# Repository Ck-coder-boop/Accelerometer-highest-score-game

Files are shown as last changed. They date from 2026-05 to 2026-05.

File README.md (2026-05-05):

# Motion-Based Reaction Game (STM32)

## Overview
This project implements a motion-controlled reaction game using an STM32 microcontroller.  
The user responds to directional prompts by tilting the device, with performance tracked through a scoring and high-score system.

The system integrates multiple peripherals including an accelerometer, display, RGB LED, and push button, with additional features such as timing constraints, input filtering, and low-power idle behaviour.

---

## Circuit Schematic
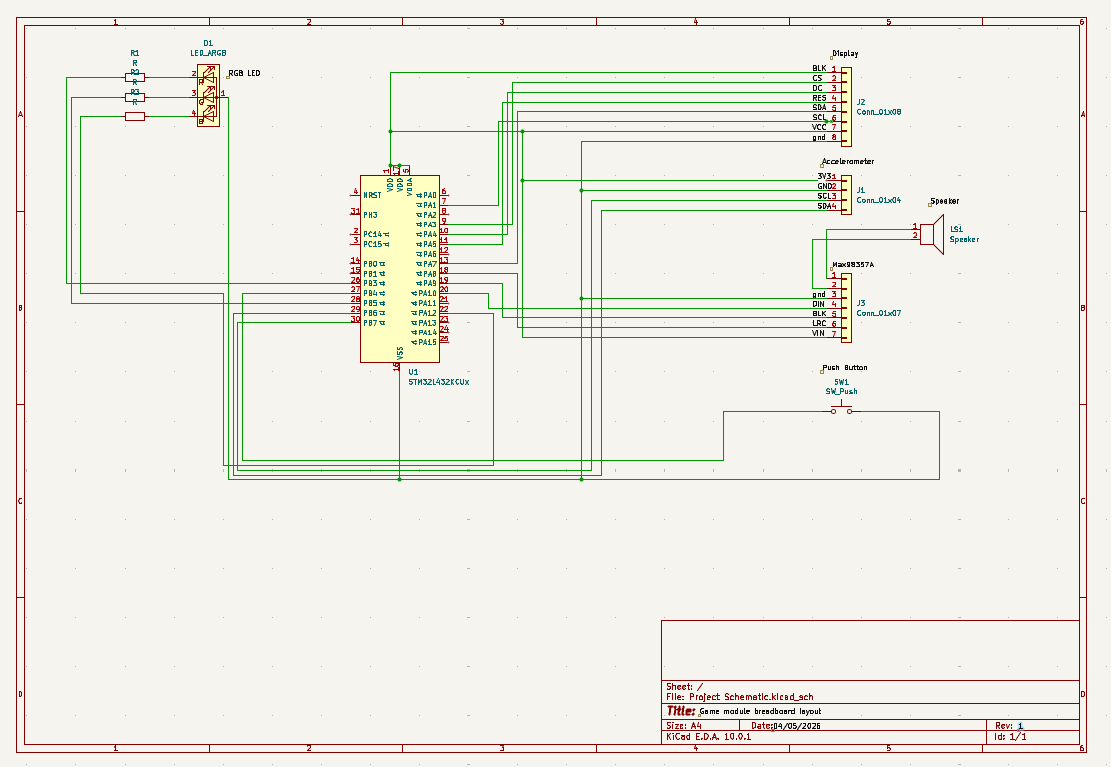
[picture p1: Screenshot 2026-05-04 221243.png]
Circuit schematic


---

## Hardware Components
- **STM32 Nucleo-L432KC** – Main controller handling logic and timing  
- **Accelerometer (I2C)** – Detects motion and tilt direction  
- **Push Button** – Starts the game and wakes the system  
- **RGB LED** – Indicates system state (idle, active, result)  
- **TFT Display (SPI)** – Displays instructions and score  
- **MAX98357A Audio Amplifier (Experimental)** – Attempted audio output  

---

## Documentation
- 📄 [Project Report](Embedded%20Systems%20Project%202.pdf)  
- 📝 [Rough Weekly Notes](Rough_notes.txt)  
- 🎥 [Demonstration Video](https://youtu.be/MFnngxhUEXM)  

---

## Source Code

### Core Application
- [main.c](main.c) – Main game logic, timing, and state control  

### Peripheral Drivers
- [display.c](display.c) / [display.h](display.h) – TFT display control (text, graphics)  
- [i2c.c](i2c.c) / [i2c.h](i2c.h) – I2C communication (accelerometer interface)  
- [spi.c](spi.c) / [spi.h](spi.h) – SPI communication (display interface)  
- [eeng1030_lib.c](eeng1030_lib.c) / [eeng1030_lib.h](eeng1030_lib.h) – Utility functions (GPIO, timing, delays)  

### Data Files
- [sound_array.h](sound_array.h) – Stored audio sample data (experimental playback)  

---

## Hardware Files
- 📐 [Schematic (PDF)](Schematicpdf.pdf)  
- 🖼️ [Breadboard Setup Image](Screenshot%202026-05-04%20221243.png)  

---

## System Features
- Motion-based input using accelerometer  
- Direction detection (left, right, forward, back)  
- Score and high-score tracking  
- Timeout-based gameplay  
- Neutral-zone filtering to prevent repeated inputs  
- RGB LED state indication  
- Low-power idle mode using CPU sleep (WFI)  
- Experimental audio playback using I2S  

---

## Notes
Audio output was investigated using a MAX98357A I2S amplifier.  
Although signal activity was observed, reliable playback was not achieved due to strict timing requirements for I2S communication when implemented in software. As a result, audio functionality was treated as experimental and was not included in the final system operation.

---

## Repository Structure (Summary)
- `main.c` → Game logic and control  
- Peripheral files → Hardware interfacing  
- `sound_array.h` → Audio data  
- Report + notes → Documentation  
- Schematic + image → Hardware design

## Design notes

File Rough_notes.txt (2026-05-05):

Week 1 – Setup and Planning
Set up STM32 environment and got previous assignment code running again
Initially wasn’t fully sure what direction to take with the project
Decided on a motion-based reaction game using the accelerometer
Didn’t get much actual implementation done this week

This week was mainly planning and getting everything working again from the previous assignment.

Week 2 – Basic Hardware + Early Issues
Started wiring up components on the breadboard
First attempt at display and button didn’t work properly
Spent time checking wiring with multimeter and fixing connections
Got button input working after fixing pull-up configuration
Display eventually worked after rechecking SPI connections

Progress was slower than expected due to wiring issues and getting used to the hardware again.

Week 3 – Core Game Logic
Got accelerometer readings working using I2C
Initially values were unstable → adjusted scaling and thresholds
First attempt at tilt detection was too sensitive
Added thresholds to detect left/right/forward/back properly
Implemented basic game loop
Tried input without neutral filtering → caused repeated triggering
Fixed this by adding a neutral zone before next input

This week involved a lot of trial and error to get reliable motion detection.

Week 4 – Features + Debugging
Added scoring system and high score tracking
Implemented timeout logic using millisecond timer
Button debounce added after noticing multiple triggers
RGB LED added for system state feedback
Tried adding audio output:
First tested speaker directly → no proper output
Created sound array and attempted playback → very weak signal
Added MAX98357A amplifier → only small click/buzz heard
Concluded issue likely due to I2S timing not being accurate
Left audio as experimental and focused on main functionality

Final week focused on refining the system and solving integration issues. Audio was attempted but not fully successful.

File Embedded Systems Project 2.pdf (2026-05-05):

# Embedded Systems Project 2 Improvements and Additional Features

EENG1030

Conor King – C22303056

Last Updated 05/05/2026

## Contents

This project presents a motion-based reaction game implemented on an STM32 microcontroller. The system uses an accelerometer to detect directional input and challenges the user to respond within a time constraint. Visual feedback is provided via an OLED display and RGB LED, while a high-score system tracks performance. Additional features include

Embedded systems are widely used in interactive applications requiring real-time input processing. This project builds on previous work by developing a motion-controlled reaction game using an STM32 platform. The system integrates multiple peripherals including an accelerometer, display, and LED indicators to create an interactive user experience. The objective was to design a responsive system with clear feedback, timing constraints, and

7.13 Audio Limitation | 11
Figure 1 Image of Real-Life Breadboard | 6
Figure 2 Schematic Design | 7

# 1. Abstract

This project presents a motion-based reaction game implemented on an STM32 microcontroller. The system uses an accelerometer to detect directional input and challenges the user to respond within a time constraint. Visual feedback is provided via an OLED display and RGB LED, while a high-score system tracks performance. Additional features include timeout logic, neutral position filtering, and low-power idle operation.

# 2. Introduction

Embedded systems are widely used in interactive applications requiring real-time input processing. This project builds on previous work by developing a motion-controlled reaction game using an STM32 platform. The system integrates multiple peripherals including an accelerometer, display, and LED indicators to create an interactive user experience. The objective was to design a responsive system with clear feedback, timing constraints, and efficient operation.

# 3. System Overview

- User presses button → game starts
- Display shows direction
- User tilts device
- System checks correctness
- Score updates
- Timeout or wrong input ends game
- High score stored

# 4. Hardware Description (Fig. 1)

## STM32 Nucleo (Controller)

- Acts as the central control unit of the system
- Executes all game logic, timing functions, and state transitions
- Interfaces with all peripherals (I2C, SPI, GPIO)
- Processes accelerometer data and determines user actions
The STM32 is responsible for coordinating all inputs and outputs in real time, ensuring that the system responds immediately to user interaction.

## Accelerometer (I2C)

- Measures acceleration in X and Y axes
- Used to detect directional tilt (left, right, forward, back)
- Provides the primary user input mechanism
- Communicates with STM32 via I2C protocol
The accelerometer replaces traditional buttons by allowing motion-based control, forming the core interaction method of the game.

## OLED Display (SPI)

- Displays game instructions (direction prompts)
- Shows current score and high score
- Provides real-time visual feedback to the user
- Communicates via SPI for fast data transfer
The display serves as the main user interface, allowing the player to understand system prompts and monitor performance.

## Push Button

- Used to start the game
- Wakes the system from idle (low-power mode)
- Configured with internal pull-up resistor
- Provides a simple digital input to the STM32
The push button acts as the system trigger, ensuring controlled startup and preventing accidental activation.

## RGB LED

- Provides quick visual indication of system state
- Colour-coded states:
- Red → Idle / waiting
- Blue → Game active
- Green → End of round
- Controlled via GPIO outputs
The RGB LED provides immediate feedback without needing to look at the display, improving usability and responsiveness.

## Speaker / Audio Module (Experimental)

- Intended to provide audio feedback for events such as high score
- Driven using digital signals from the STM32

- Attempted implementation using I2S (MAX98357A amplifier)
- Used sound data array for playback
The audio system was designed to enhance user feedback; however, due to strict timing requirements for I2S communication, reliable playback was not achieved. The module remains part of the design but is not critical to core functionality.

## Breadboard and Wiring

- Used to prototype and interconnect all components
- Provides flexible layout for rapid testing and modification
- Distributes power (3.3 V and GND) across all modules
The breadboard enables quick hardware iteration and testing, which was essential during debugging and system integration.

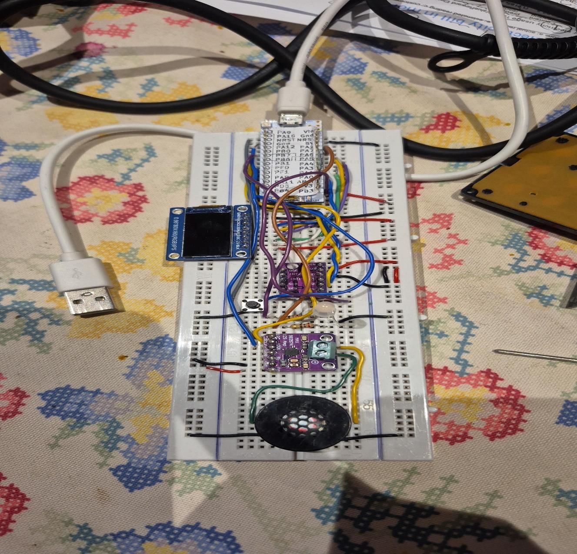
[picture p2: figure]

Figure 1 Image of Real-Life Breadboard

# 5. Circuit Schematic (Fig. 2)

The circuit schematic (Fig. 2) shows the interconnection between the STM32 microcontroller and all peripherals. Communication protocols include I2C for the accelerometer and SPI for the display. GPIO pins are used for button input, LED control, and audio output. Proper power and ground distribution are maintained across the system.

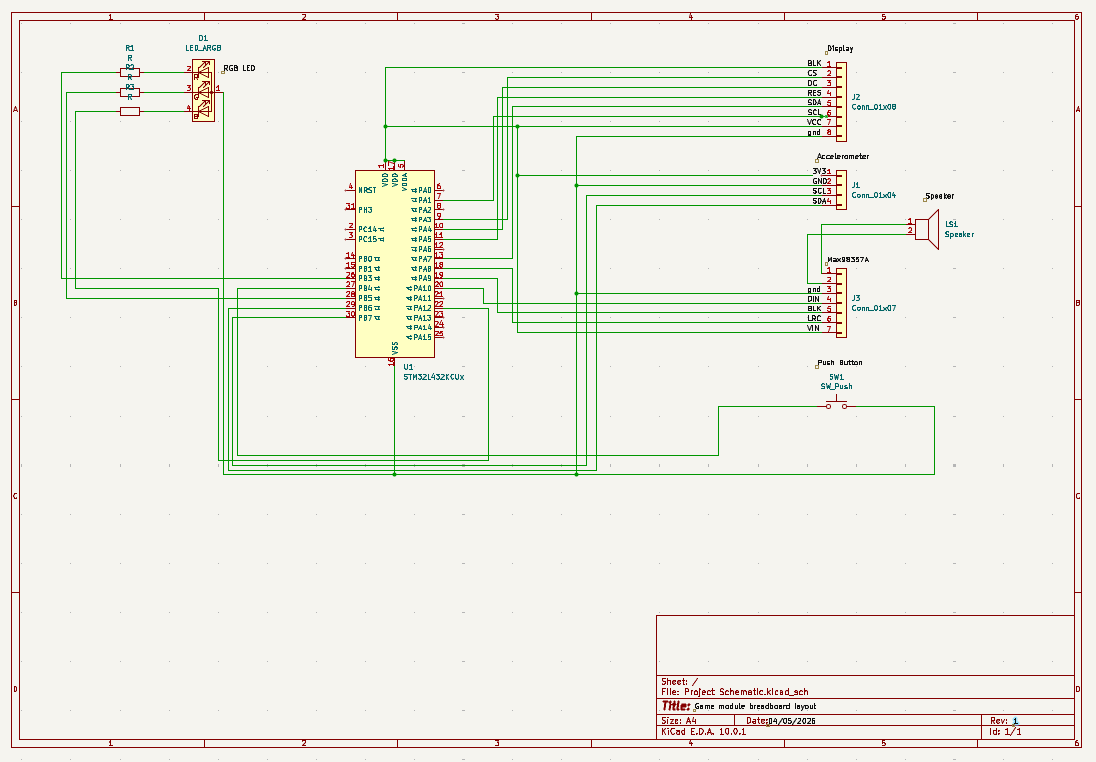
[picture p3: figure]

Figure 2 Schematic Design

# 6. Troubleshooting and Problem Solving

The system was developed using an incremental testing approach, where each component was verified individually before full integration. Basic electrical checks were first carried out using a multimeter to confirm correct voltage levels, common grounding, and continuity across the breadboard. Individual modules such as the push button, RGB LED, display, and accelerometer were then tested using small standalone code segments to ensure correct operation. This approach allowed faults to be isolated quickly and ensured that any issues encountered during full system integration were more likely related to software logic or communication timing rather than wiring errors.
During integration, timing-related behaviour and input reliability were refined through testing. The accelerometer thresholds were adjusted based on observed readings to ensure that only deliberate movements were detected, while a neutral zone was implemented to prevent repeated triggering. Buttons debounce delays were also introduced to eliminate false inputs. Visual feedback through the RGB LED was verified to correctly represent system states, and timeout logic was tested to ensure the game ended correctly when no input was detected within the specified time window.
A significant issue was encountered with the speaker and audio output. The speaker was initially tested directly from a GPIO output, where no meaningful audio signal was produced. A sound array generated externally was then used to drive the speaker, but only a very weak or brief signal was observed. When the MAX98357A amplifier module was introduced, a small click or buzz was detected, indicating that some signal was present, but no clear audio playback was achieved. This suggests that while the data was being transmitted, the timing requirements for proper I2S communication were not being met. As a result, audio functionality was considered experimental and was not relied upon for the final system, although the testing process confirmed partial signal activity and ruled out complete hardware failure. Time was no doubt a factor here too and some attempts were used just with small segments of code to get the operation working but again it seemingly refused to work.

# 7. Software Design

The software was structured so that each major function of the system is handled separately. The main program controls the game flow, while separate functions are used for accelerometer reading, tilt detection, display updates, RGB LED feedback, low-power idle mode, and experimental audio playback.

## 7.1 Timing Constants

#define ROUND_TIME_MS 4000

#define IDLE_SLEEP_MS 10000

#define DEBOUNCE_MS 250

#define RESULT_DISPLAY_MS 2000

These constants define the main timing behaviour of the system. The player has four seconds to respond to each displayed instruction. A debounce delay is used to prevent one button press from being detected multiple times, and the result screen remains visible for two seconds before returning to idle.

## 7.2 Button Start Logic

button = (BUTTON_PORT->IDR & (1 << BUTTON_PIN)) ? 1 : 0;

if ((last_button == 1) && (button == 0) && !running)
{
running = 1;
score = 0;
ready = 1;

action = next_action();
round_start_time = milliseconds; }

The push button uses an internal pull-up resistor, meaning the input is normally high and becomes low when pressed. The code detects this falling edge and starts a new game only when the system is not already running.

## 7.3 Random Action Generation

static uint8_t next_action(void)
{
static uint8_t count = 0;
count++;

return (uint8_t)((milliseconds + count * 7) % 4);
}
This function generates the next movement instruction. The system uses the current millisecond timer and an increasing counter to vary the output. The result is limited to four possible values: left, right, forward, and back.

## 7.4 Accelerometer Tilt Detection

static uint8_t detect_tilt(int32_t x, int32_t y)
{
if (y < 200 && y > -200)
{
if (x > X_THRESHOLD) return ACT_RIGHT; if (x < -X_THRESHOLD) return ACT_LEFT; }

if (x < 300 && x > -300)
{
if (y > Y_FORWARD_THRESHOLD) return ACT_FORWARD; if (y < Y_BACK_THRESHOLD) return ACT_BACK;
}

return ACT_NONE;
}
The accelerometer values are compared against threshold values to decide which direction the user has tilted the device. X-axis values are used for left and right movement, while Y-axis values are used for forward and back movement. If no threshold is exceeded, no action is detected.

## 7.5 Neutral Zone Filtering

if ((x < X_NEUTRAL_HIGH && x > X_NEUTRAL_LOW) &&
(y < Y_NEUTRAL_HIGH && y > Y_NEUTRAL_LOW))
{
ready = 1;
}

A neutral zone is used so that one tilt is not counted repeatedly. After a movement is detected, the user must return the board close to its neutral position before another input can be accepted.

## 7.6 Timeout Logic

if ((milliseconds - round_start_time) > ROUND_TIME_MS)
{
running = 0;
rgb_green();
draw_fail(score, high);
}
The timeout logic ends the game if the user does not respond within the allowed time. This creates the reaction-game behaviour and prevents the system from waiting indefinitely for input.

## 7.7 High Score Logic

if (score > high)
{
high = score;
rgb_green();
draw_high(score);
play_sound_file();
}
The high score is stored during runtime. If the player beats the previous high score, the display updates to show the new score and the stored audio sample is attempted through the audio output system.

## 7.8 RGB LED State Feedback

rgb_red(); // idle / waiting
rgb_blue(); // game active
rgb_green(); // result screen
The RGB LED acts as a quick system status indicator. Red shows the system is idle, blue shows the game is active, and green shows the end/result state. This gives feedback even when the user is not focused on the display.

## 7.9 Low-Power Idle Mode

static void enter_idle_sleep(void)
{
rgb_off();
__WFI();
}
The system enters a light sleep state after a period of inactivity. The __WFI() instruction places the CPU into a wait-for-interrupt mode, reducing unnecessary activity while preserving variables such as the high score.

## 7.10 Audio Sample Array

#include "sound_array.h"

const int16_t sound_data[] = {
3, 2, -1, -5, 5, -1,
};

const unsigned int sound_length =
sizeof(sound_data) / sizeof(sound_data[0]);
The audio sample is stored in a separate header file as signed 16-bit values. These values were generated from an external audio file and converted into a C array. This allows the sound data to be stored directly in the microcontroller flash memory.

## 7.11 Audio Playback Attempt

static void play_sound_file(void)
{
for (uint32_t i = 0; i < sound_length; i++) {
int16_t s = sound_data[i] * 3; i2s_send_stereo(s, s);
}
}
This function loops through the stored audio sample and sends each value to the audio output function. The sample is multiplied to increase amplitude before being sent to both left and right audio channels.

## 7.12 I2S Bit Transmission

static void i2s_send_stereo(int16_t left, int16_t right)
{
I2S_LRC_PORT->ODR &= ~(1 << I2S_LRC_PIN); i2s_send_word(left);

I2S_LRC_PORT->ODR |= (1 << I2S_LRC_PIN);
i2s_send_word(right);
}
The MAX98357A audio module uses I2S communication, requiring separate signals for bit clock, left/right clock, and data. This function attempts to send left and right channel audio samples by manually controlling the GPIO pins.

## 7.13 Audio Limitation

Again, although the audio sample was successfully stored and transmitted in software, reliable playback was not achieved. The MAX98357A requires accurately timed I2S signals, and software-based bit-banging was not accurate enough to produce clear sound. It is still unclear what the issue was.

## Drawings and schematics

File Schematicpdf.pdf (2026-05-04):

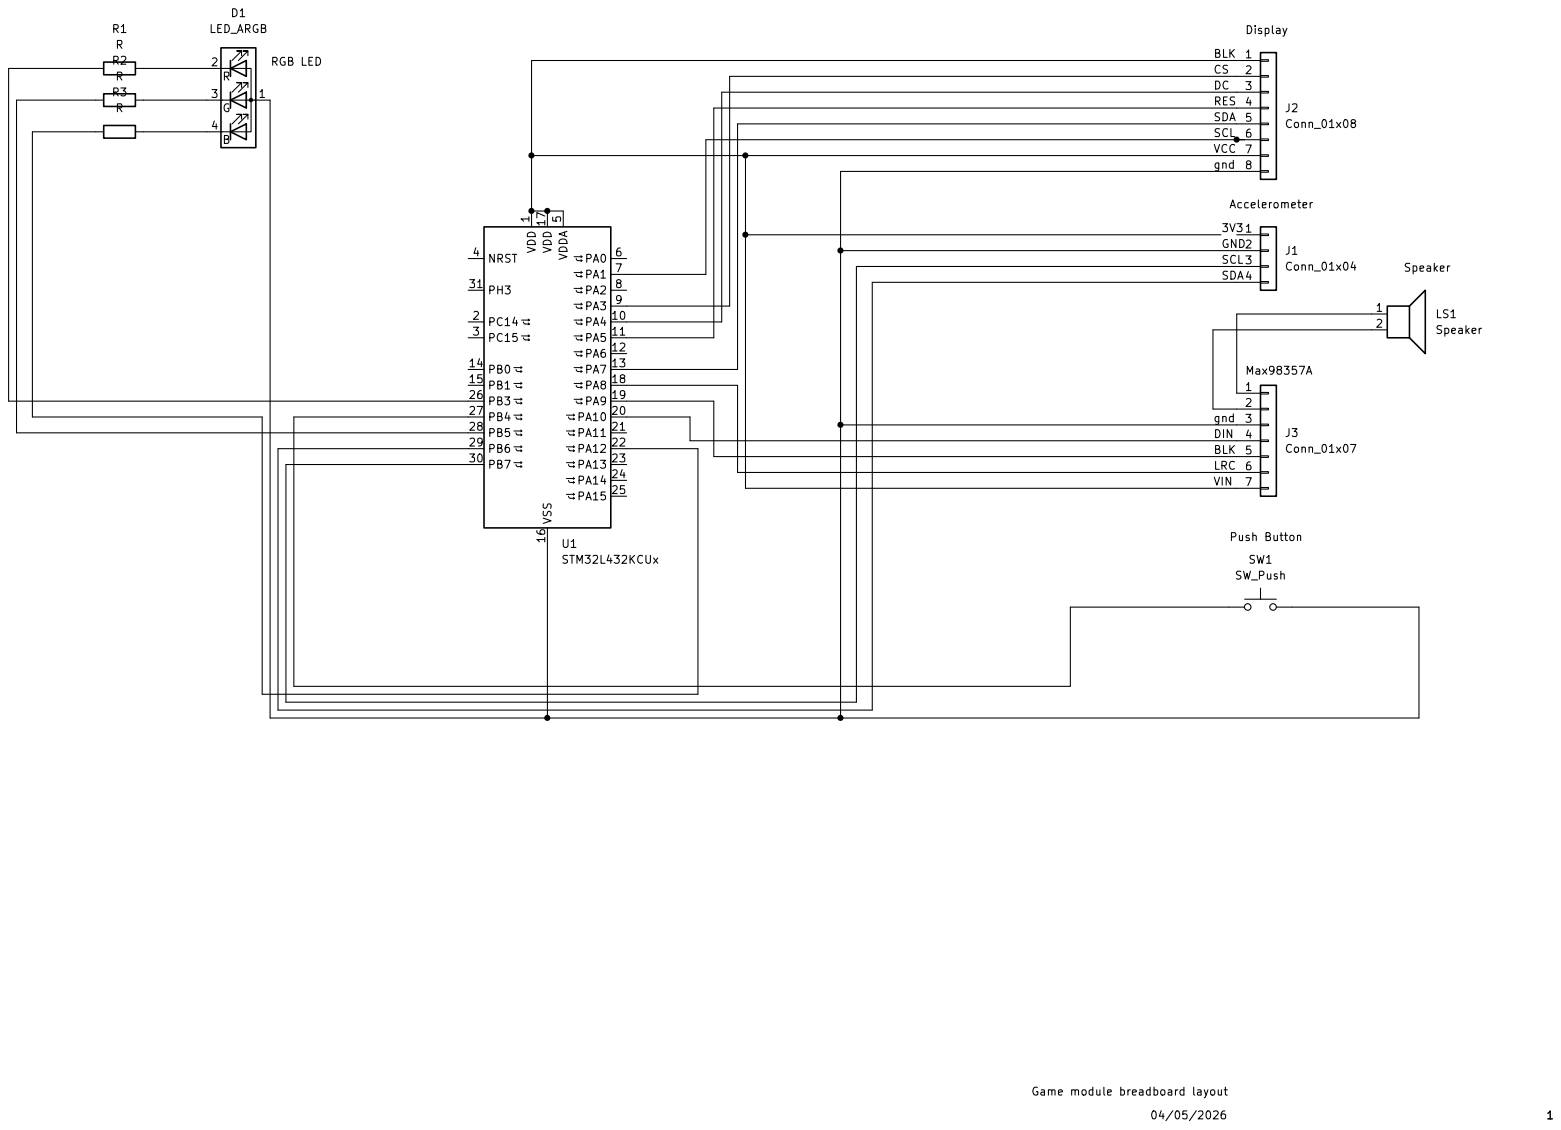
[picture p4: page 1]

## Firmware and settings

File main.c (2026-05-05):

#include "eeng1030_lib.h"
#include "display.h"
#include "i2c.h"
#include <stdint.h>
#include <stdio.h>
#include <stm32l432xx.h>

#include "sound_array.h"

#define ACCEL_ADDR 0x69

#define ACT_LEFT     0
#define ACT_RIGHT    1
#define ACT_FORWARD  2
#define ACT_BACK     3
#define ACT_NONE     255

#define X_THRESHOLD 900
#define Y_FORWARD_THRESHOLD 800
#define Y_BACK_THRESHOLD   -900

#define X_NEUTRAL_HIGH  300
#define X_NEUTRAL_LOW  -300
#define Y_NEUTRAL_HIGH  200
#define Y_NEUTRAL_LOW  -200

#define BUTTON_PORT GPIOB
#define BUTTON_PIN  4

#define RGB_R_PORT GPIOB
#define RGB_R_PIN  3
#define RGB_G_PORT GPIOA
#define RGB_G_PIN  12
#define RGB_B_PORT GPIOA
#define RGB_B_PIN  11

#define I2S_BCLK_PORT GPIOA
#define I2S_BCLK_PIN  8
#define I2S_LRC_PORT  GPIOA
#define I2S_LRC_PIN   9
#define I2S_DIN_PORT  GPIOA
#define I2S_DIN_PIN   10

#define ROUND_TIME_MS      4000
#define IDLE_SLEEP_MS      10000
#define DEBOUNCE_MS        250
#define RESULT_DISPLAY_MS  2000

extern volatile uint32_t milliseconds;

static void setup(void);
static void enter_idle_sleep(void);

static void accel_init(void);
static int16_t accel_read_axis(uint8_t reg);
static uint8_t detect_tilt(int32_t x, int32_t y);

static void rgb_off(void);
static void rgb_red(void);
static void rgb_green(void);
static void rgb_blue(void);
static void rgb_yellow(void);

static void draw_start(uint8_t high);
static void draw_action(uint8_t act, uint8_t score, uint8_t high);
static void draw_fail(uint8_t score, uint8_t high);
static void draw_high(uint8_t score);

static uint8_t next_action(void);

static void i2s_gpio_init(void);
static void i2s_send_bit(uint8_t bit);
static void i2s_send_word(int16_t sample);
static void i2s_send_stereo(int16_t left, int16_t right);
static void play_sound_file(void);

int main(void)
{
    uint8_t running = 0;
    uint8_t last_button = 1;
    uint8_t button;

    uint8_t action = ACT_NONE;
    uint8_t detected = ACT_NONE;

    uint8_t ready = 1;
    uint8_t score = 0;
    uint8_t high = 0;

    uint32_t round_start_time = 0;
    uint32_t last_activity_time = 0;

    int16_t x_raw, y_raw;
    int32_t x, y;

    setup();
    accel_init();

    rgb_blue();
    draw_start(high);

    last_activity_time = milliseconds;

    while (1)
    {
        button = (BUTTON_PORT->IDR & (1 << BUTTON_PIN)) ? 1 : 0;

        /*
         * Button is active-low because the internal pull-up is enabled.
         * A falling edge starts the game from the idle state.
         */
        if ((last_button == 1) && (button == 0) && !running)
        {
            running = 1;
            score = 0;
            ready = 1;

            action = next_action();
            round_start_time = milliseconds;
            last_activity_time = milliseconds;

            rgb_yellow();
            draw_action(action, score, high);

            delay_ms(DEBOUNCE_MS);
        }

        last_button = button;

        if (running)
        {
            /*
             * Read accelerometer X and Y axes.
             * Raw values are scaled to approximate acceleration values.
             */
            x_raw = accel_read_axis(0x12);
            y_raw = accel_read_axis(0x14);

            x = ((int32_t)x_raw * 981) / 16384;
            y = ((int32_t)y_raw * 981) / 16384;

            /*
             * The ready flag prevents one tilt from being counted repeatedly.
             * The player must return the device to a neutral position before
             * another movement is accepted.
             */
            if ((x < X_NEUTRAL_HIGH && x > X_NEUTRAL_LOW) &&
                (y < Y_NEUTRAL_HIGH && y > Y_NEUTRAL_LOW))
            {
                ready = 1;
            }

            detected = detect_tilt(x, y);

            if (ready && detected != ACT_NONE)
            {
                ready = 0;
                last_activity_time = milliseconds;

                if (detected == action)
                {
                    /*
                     * Correct input:
                     * score increases and a new random instruction is shown.
                     */
                    score++;

                    rgb_green();
                    delay_ms(200);

                    action = next_action();
                    round_start_time = milliseconds;

                    rgb_yellow();
                    draw_action(action, score, high);
                }
                else
                {
                    /*
                     * Incorrect input:
                     * game ends. If the score beats the high score,
                     * the stored audio array is played.
                     */
                    running = 0;

                    if (score > high)
                    {
                        high = score;
                        rgb_green();
                        draw_high(score);
                        play_sound_file();
                    }
                    else
                    {
                        rgb_red();
                        draw_fail(score, high);
                    }

                    delay_ms(RESULT_DISPLAY_MS);
                    rgb_blue();
                    draw_start(high);
                    last_activity_time = milliseconds;
                }
            }

            /*
             * Timeout:
             * if the player does not respond in time, the game ends.
             */
            if ((milliseconds - round_start_time) > ROUND_TIME_MS)
            {
                running = 0;

                if (score > high)
                {
                    high = score;
                    rgb_green();
                    draw_high(score);
                    play_sound_file();
                }
                else
                {
                    rgb_red();
                    draw_fail(score, high);
                }

                delay_ms(RESULT_DISPLAY_MS);
                rgb_blue();
                draw_start(high);
                last_activity_time = milliseconds;
            }
        }
        else
        {
            /*
             * Low-power idle behaviour:
             * after a period of inactivity, outputs are turned off and the CPU
             * waits for the next interrupt. A button press wakes the system.
             */
            if ((milliseconds - last_activity_time) > IDLE_SLEEP_MS)
            {
                enter_idle_sleep();
                last_activity_time = milliseconds;
                draw_start(high);
                rgb_blue();
            }
        }

        delay_ms(50);
    }
}

static void enter_idle_sleep(void)
{
    rgb_off();

    /*
     * WFI places the CPU into sleep until an interrupt occurs.
     * SysTick or external interrupt activity can wake the device.
     * This is a light sleep mode and does not erase variables such as high score.
     */
    __WFI();
}

static uint8_t next_action(void)
{
    static uint8_t count = 0;
    count++;

    /*
     * Lightweight pseudo-random action generation using time and counter.
     * This avoids repeating a fixed sequence each time the game runs.
     */
    return (uint8_t)((milliseconds + count * 7) % 4);
}

static uint8_t detect_tilt(int32_t x, int32_t y)
{
    if (y < 200 && y > -200)
    {
        if (x > X_THRESHOLD) return ACT_RIGHT;
        if (x < -X_THRESHOLD) return ACT_LEFT;
    }

    if (x < 300 && x > -300)
    {
        if (y > Y_FORWARD_THRESHOLD) return ACT_FORWARD;
        if (y < Y_BACK_THRESHOLD) return ACT_BACK;
    }

    return ACT_NONE;
}

/* ===================== Display Functions ===================== */

static void draw_start(uint8_t high)
{
    uint16_t black = RGBToWord(0,0,0);
    uint16_t cyan = RGBToWord(0,255,255);
    uint16_t white = RGBToWord(255,255,255);

    char buf[16];

    fillRectangle(0,0,160,80,black);
    printTextX2("MOTION", 30, 10, cyan, black);
    printText("PRESS BUTTON", 25, 40, white, black);

    sprintf(buf, "HIGH:%d", high);
    printText(buf, 50, 62, white, black);
}

static void draw_action(uint8_t act, uint8_t score, uint8_t high)
{
    uint16_t black = RGBToWord(0,0,0);
    uint16_t yellow = RGBToWord(255,255,0);
    uint16_t white = RGBToWord(255,255,255);

    const char* txt[] = {"LEFT", "RIGHT", "FORWARD", "BACK"};
    char buf[20];

    fillRectangle(0,0,160,80,black);
    printTextX2((char*)txt[act], 18, 28, yellow, black);

    sprintf(buf, "S:%d H:%d", score, high);
    printText(buf, 40, 65, white, black);
}

static void draw_fail(uint8_t score, uint8_t high)
{
    uint16_t black = RGBToWord(0,0,0);
    uint16_t red = RGBToWord(255,0,0);
    uint16_t white = RGBToWord(255,255,255);

    char buf[20];

    fillRectangle(0,0,160,80,black);
    printTextX2("FAIL", 40, 10, red, black);

    sprintf(buf, "S:%d H:%d", score, high);
    printText(buf, 40, 60, white, black);
}

static void draw_high(uint8_t score)
{
    uint16_t black = RGBToWord(0,0,0);
    uint16_t green = RGBToWord(0,255,0);
    uint16_t white = RGBToWord(255,255,255);

    char buf[20];

    fillRectangle(0,0,160,80,black);
    printTextX2("NEW HIGH", 8, 20, green, black);

    sprintf(buf, "SCORE:%d", score);
    printText(buf, 45, 60, white, black);
}

/* ===================== RGB LED Functions ===================== */

static void rgb_off(void)
{
    RGB_R_PORT->ODR &= ~(1 << RGB_R_PIN);
    RGB_G_PORT->ODR &= ~(1 << RGB_G_PIN);
    RGB_B_PORT->ODR &= ~(1 << RGB_B_PIN);
}

static void rgb_red(void)
{
    rgb_off();
    RGB_R_PORT->ODR |= (1 << RGB_R_PIN);
}

static void rgb_green(void)
{
    rgb_off();
    RGB_G_PORT->ODR |= (1 << RGB_G_PIN);
}

static void rgb_blue(void)
{
    rgb_off();
    RGB_B_PORT->ODR |= (1 << RGB_B_PIN);
}

static void rgb_yellow(void)
{
    rgb_off();
    RGB_R_PORT->ODR |= (1 << RGB_R_PIN);
    RGB_G_PORT->ODR |= (1 << RGB_G_PIN);
}

/* ===================== Audio Functions ===================== */

static void i2s_gpio_init(void)
{
    pinMode(I2S_BCLK_PORT, I2S_BCLK_PIN, 1);
    pinMode(I2S_LRC_PORT, I2S_LRC_PIN, 1);
    pinMode(I2S_DIN_PORT, I2S_DIN_PIN, 1);

    I2S_BCLK_PORT->ODR &= ~(1 << I2S_BCLK_PIN);
    I2S_LRC_PORT->ODR &= ~(1 << I2S_LRC_PIN);
    I2S_DIN_PORT->ODR &= ~(1 << I2S_DIN_PIN);
}

static void i2s_send_bit(uint8_t bit)
{
    if (bit)
        I2S_DIN_PORT->ODR |= (1 << I2S_DIN_PIN);
    else
        I2S_DIN_PORT->ODR &= ~(1 << I2S_DIN_PIN);

    I2S_BCLK_PORT->ODR |= (1 << I2S_BCLK_PIN);
    for (volatile int d = 0; d < 3; d++);

    I2S_BCLK_PORT->ODR &= ~(1 << I2S_BCLK_PIN);
    for (volatile int d = 0; d < 3; d++);
}

static void i2s_send_word(int16_t sample)
{
    uint16_t value = (uint16_t)sample;

    for (int bit = 15; bit >= 0; bit--)
    {
        i2s_send_bit((value >> bit) & 1);
    }
}

static void i2s_send_stereo(int16_t left, int16_t right)
{
    I2S_LRC_PORT->ODR &= ~(1 << I2S_LRC_PIN);
    i2s_send_word(left);

    I2S_LRC_PORT->ODR |= (1 << I2S_LRC_PIN);
    i2s_send_word(right);
}

static void play_sound_file(void)
{
    /*
     * The sound data is stored as signed 16-bit PCM values in sound_array.h.
     * The sample is sent to both left and right channels.
     */
    for (uint32_t i = 0; i < sound_length; i++)
    {
        int16_t s = sound_data[i] * 3;
        i2s_send_stereo(s, s);
    }

    I2S_DIN_PORT->ODR &= ~(1 << I2S_DIN_PIN);
}

/* ===================== Setup and Accelerometer ===================== */

static void setup(void)
{
    RCC->AHB2ENR |= (1 << 0) | (1 << 1);

    initClocks();
    initSysTick();
    init_display();
    initI2C();

    pinMode(BUTTON_PORT, BUTTON_PIN, 0);
    enablePullUp(BUTTON_PORT, BUTTON_PIN);

    pinMode(RGB_R_PORT, RGB_R_PIN, 1);
    pinMode(RGB_G_PORT, RGB_G_PIN, 1);
    pinMode(RGB_B_PORT, RGB_B_PIN, 1);

    i2s_gpio_init();

    rgb_off();
}

static void accel_init(void)
{
    /*
     * Write to accelerometer power/control register.
     * This places the device into the active measurement mode.
     */
    I2CStart(ACCEL_ADDR, WRITE, 2);
    I2CWrite(0x7E);
    I2CWrite(0x11);
    I2CStop();

    delay_ms(100);
}

static int16_t accel_read_axis(uint8_t reg)
{
    uint16_t low, high;

    I2CStart(ACCEL_ADDR, WRITE, 1);
    I2CWrite(reg);
    I2CReStart(ACCEL_ADDR, READ, 2);

    low = I2CRead();
    high = I2CRead();

    I2CStop();

    return (int16_t)(low | (high << 8));
}
